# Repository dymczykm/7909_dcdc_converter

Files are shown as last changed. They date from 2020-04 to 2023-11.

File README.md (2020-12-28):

# Alpine 7909 DC/DC converter
An improved DC/DC converter design for Alpine 7909.

Uses a Traco 6W converter to get symmetric +/-12V and then ultralow noise, ultrahigh PSRR linear regulators (LT3045, LT3094) to regulate the voltages down to +/-10V.

The board is smaller than the original and fits nicely into the space available.

**Warning** The PCBs have not been tested as of now, use at your own risk.

## 3D view

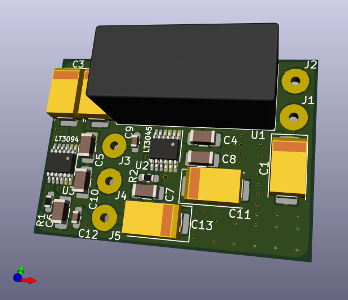
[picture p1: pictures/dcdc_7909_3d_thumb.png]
3D render


## Component list

Most components specific to this are contained in the [CSV file](digikey_bom.csv). Please note that it does not contain components I had already at hand, so double check it against the schematic.

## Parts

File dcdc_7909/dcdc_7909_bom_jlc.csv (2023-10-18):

Comment | Designator | Footprint | LCSC Part #
22u | C1,C2,C3,C6,C8,C9,C15,C16,C17,C19,C21,C22,C24,C26 | C_1210_3225Metric | C426653
100n | C4,C7,C10,C13,C14 | C_0402_1005Metric | C307331
2u2 | C5,C12 | C_1206_3216Metric | C50254
10n | C11,C20,C25 | C_0402_1005Metric | C15195
22u | C18,C23 | C_1206_3216Metric | C12891
P6SMB20A | D1 | D_SMB | C719321
600Ω@100MHz | FB1,FB2 | R_0805_2012Metric | C1017
2M2 | R1 | R_0402_1005Metric | C11490
300k | R2 | R_0402_1005Metric | C334752
499k 1% | R3 | R_0402_1005Metric | C407728
47k 1% | R4 | R_0402_1005Metric | C25792
3M32 | R5 | R_0402_1005Metric | C477691
430k | R6 | R_0402_1005Metric | C25786
6k81 | R7 | R_0402_1005Metric | C284661
19k1 1% | R8 | R_0402_1005Metric | C52036
1k78 1% | R9 | R_0402_1005Metric | C284379
100k 1% | R10,R12 | R_0603_1608Metric | C25803
1k | R11,R13 | R_0402_1005Metric | C11702
LM2940-SOT223-15 | U1 | SOT-223 | C81094
MAX17579ATC+ | U3 | 21-0664_TD1233&plus_1C_MXM | C5691155
LT3045xMSE | U4 | MSOP-12-1EP_3x4mm_P0.65mm_EP1.65x2.85mm | C666577
LT3094xMSE | U5 | MSOP-12-1EP_3x4mm_P0.65mm_EP1.65x2.85mm | C498217

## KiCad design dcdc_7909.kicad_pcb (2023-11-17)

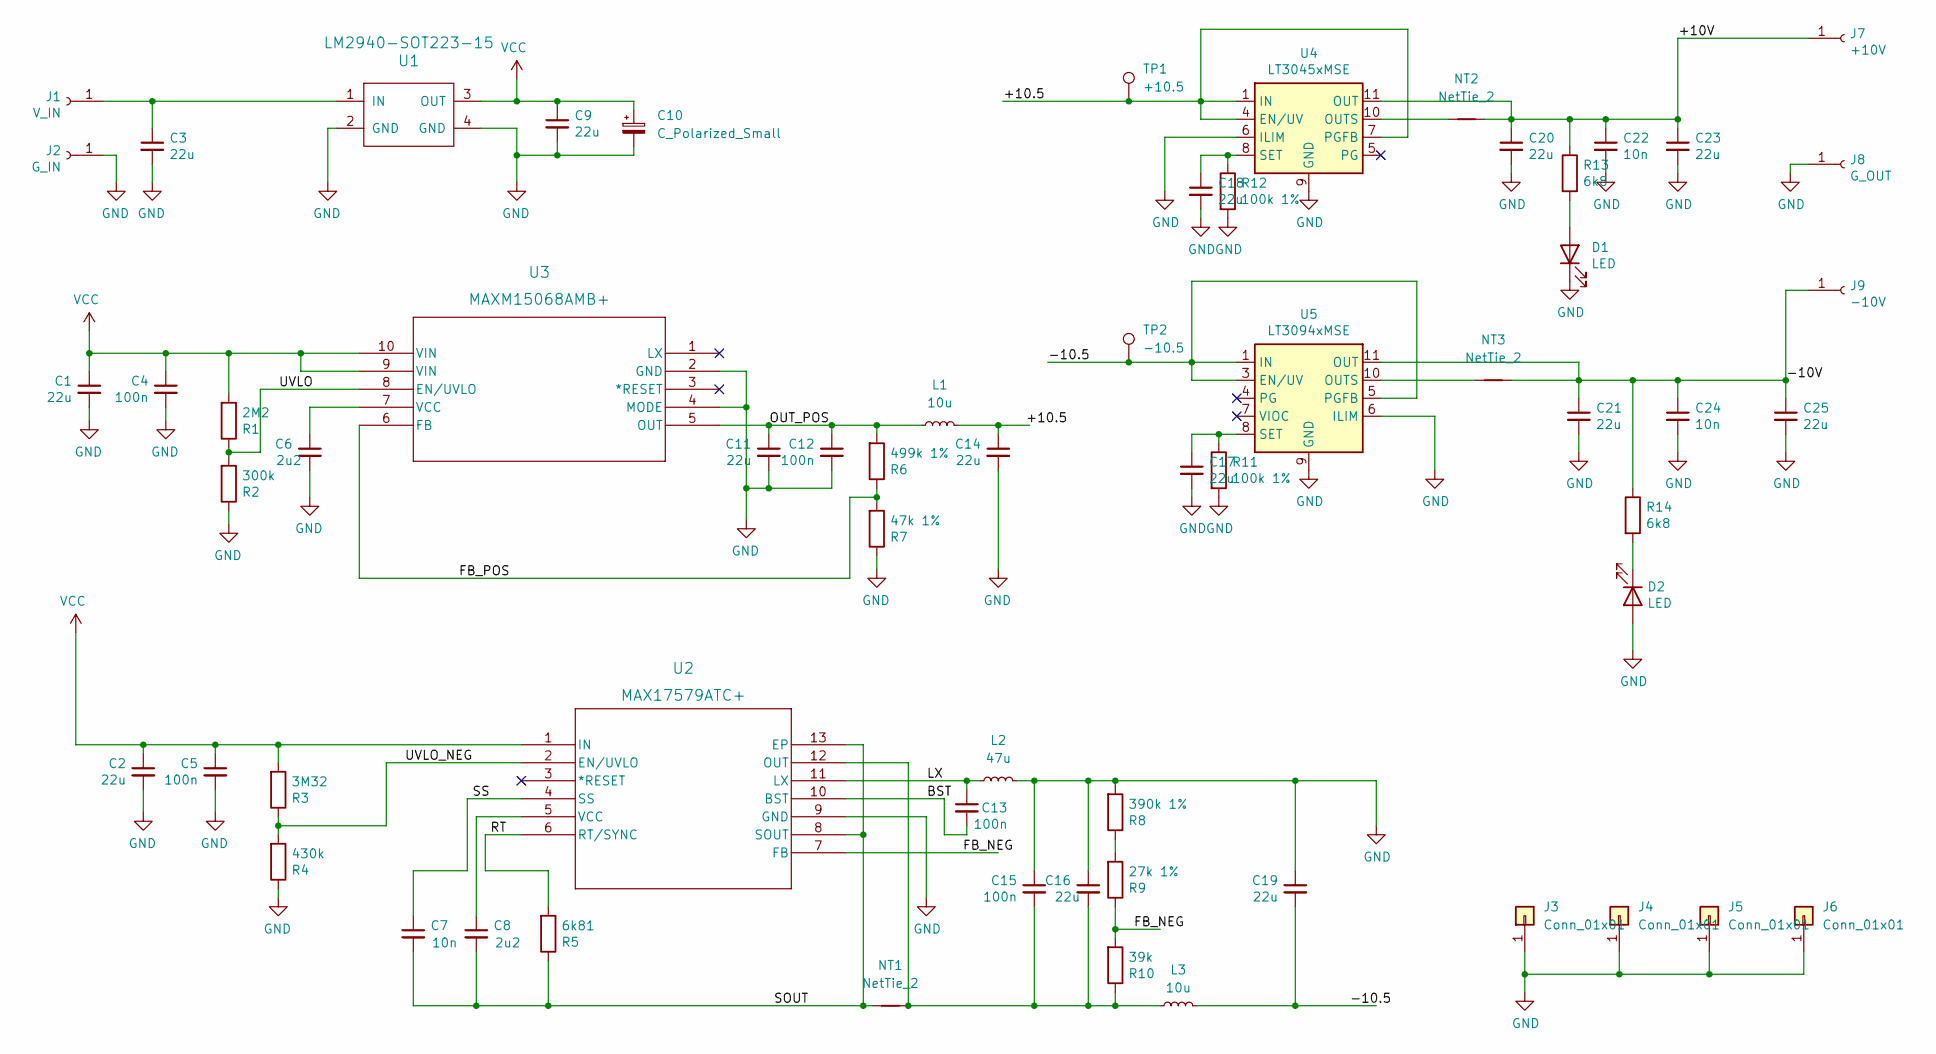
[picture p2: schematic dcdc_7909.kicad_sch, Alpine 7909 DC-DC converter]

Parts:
C1, C2, C3, C9, C11, C14, C16, C19, C20, C21, C23, C25: 22u; C_1210_3225Metric; LCSC C426653
C4, C5, C12, C13, C15: 100n; C_0402_1005Metric; LCSC C307331
C6, C8: 2u2; C_1206_3216Metric; LCSC C50254
C7, C22, C24: 10n; C_0402_1005Metric; LCSC C15195
C10: C_Polarized_Small; CP_Elec_6.3x5.9
C17, C18: 22u; C_1206_3216Metric; LCSC C12891
D1, D2: LED; LED_0805_2012Metric_Pad1.15x1.40mm_HandSolder; LCSC DO NOT POPULATE
J1: V_IN; SolderWire-0.75sqmm_1x01_D1.25mm_OD3.5mm; LCSC DO NOT POPULATE
J2: G_IN; SolderWire-0.75sqmm_1x01_D1.25mm_OD3.5mm; LCSC DO NOT POPULATE
J3, J4, J5, J6: Conn_01x01; SolderWirePad_1x01_SMD_1x2mm; LCSC DO NOT POPULATE
J7: +10V; SolderWire-0.75sqmm_1x01_D1.25mm_OD3.5mm; LCSC DO NOT POPULATE
J8: G_OUT; SolderWire-0.75sqmm_1x01_D1.25mm_OD3.5mm; LCSC DO NOT POPULATE
J9: -10V; SolderWire-0.75sqmm_1x01_D1.25mm_OD3.5mm; LCSC DO NOT POPULATE
L1, L3: 10u; L_0805_2012Metric; LCSC DO NOT POPULATE
L2: 47u; Wurth 74408063680; LCSC DO NOT POPULATE
NT1, NT2, NT3: NetTie_2; NetTie-2_SMD_Pad0.5mm; LCSC DO NOT POPULATE
R1: 2M2; R_0402_1005Metric; LCSC C11490
R2: 300k; R_0402_1005Metric; LCSC C334752
R3: 3M32; R_0402_1005Metric; LCSC C477691
R4: 430k; R_0402_1005Metric; LCSC C25786
R5: 6k81; R_0402_1005Metric; LCSC C284661
R6: 499k 1%; R_0402_1005Metric; LCSC C407728
R7: 47k 1%; R_0402_1005Metric; LCSC C25792
R8: 390k 1%; R_0402_1005Metric; LCSC C52036
R9: 27k 1%; R_0402_1005Metric; LCSC C52036
R10: 39k; R_0402_1005Metric; LCSC C284379
R11, R12: 100k 1%; R_0603_1608Metric; LCSC C25803
R13, R14: 6k8; R_0402_1005Metric; LCSC C25917
TP1: +10.5; TestPoint_THTPad_D1.0mm_Drill0.5mm; LCSC DO NOT POPULATE
TP2: -10.5; TestPoint_THTPad_D1.0mm_Drill0.5mm; LCSC DO NOT POPULATE
U1: LM2940-SOT223-15; SOT-223; LCSC C81094
U2: MAX17579ATC+; 21-0664_TD1233&plus_1C_MXM; LCSC C5691155
U3: MAXM15068AMB+; 10-eMGA (3x2.6); LCSC DO NOT POPULATE
U4: LT3045xMSE; MSOP-12-1EP_3x4mm_P0.65mm_EP1.65x2.85mm; LCSC C666577
U5: LT3094xMSE; MSOP-12-1EP_3x4mm_P0.65mm_EP1.65x2.85mm; LCSC C498217

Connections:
/+10.5: C14.1, L1.1, TP1.1, U4.1 (IN), U4.2 (IN), U4.3 (IN), U4.4 (EN/UV), U4.7 (PGFB)
/+10V: C20.1, C22.1, C23.1, J7.1, NT2.2, R13.1, U4.11 (OUT), U4.12 (OUT)
/-10.5: C19.2, L3.1, TP2.1, U5.1 (IN), U5.2 (IN), U5.3 (EN/UV), U5.5 (PGFB), U5.13 (IN)
/-10V: C21.1, C24.1, C25.1, J9.1, NT3.2, R14.1, U5.11 (OUT), U5.12 (OUT)
/BST: C13.2, U2.10 (BST)
/FB_NEG: R9.1, R10.2, U2.7 (FB)
/FB_POS: R6.1, R7.2, U3.6 (FB)
/LX: C13.1, L2.1, U2.11 (LX)
/OUT_POS: C11.1, C12.1, L1.2, R6.2, U3.5 (OUT)
/RT: R5.2, U2.6 (RT/SYNC)
/SOUT: C7.2, C8.2, NT1.1, R5.1, U2.8 (SOUT), U2.13 (EP)
/SS: C7.1, U2.4 (SS)
/UVLO: R1.1, R2.2, U3.8 (EN/UVLO)
/UVLO_NEG: R3.1, R4.2, U2.2 (EN/UVLO)
GND: C1.2, C2.2, C3.2, C4.2, C5.2, C6.2, C9.2, C10.2, C11.2, C12.2, C14.2, C15.1, C16.1, C17.2, C18.2, C19.1, C20.2, C21.2, C22.2, C23.2, C24.2, C25.2, D1.1 (K), D2.2 (A), J2.1, J3.1, J4.1, J5.1, J6.1, J8.1, L2.2, R2.1, R4.1, R7.1, R8.2, R11.2, R12.2, U1.2 (GND), U1.4 (GND), U2.9 (GND), U3.2 (GND), U3.4 (MODE), U4.6 (ILIM), U4.9 (GND), U4.13 (GND), U5.6 (ILIM), U5.9 (GND)
unnamed: C3.1, J1.1, U1.1 (IN)
unnamed: C6.1, U3.7 (VCC)
unnamed: C8.1, U2.5 (VCC)
unnamed: C15.2, C16.2, L3.2, NT1.2, R10.1, U2.12 (OUT)
unnamed: C17.1, R11.1, U5.8 (SET)
unnamed: C18.1, R12.1, U4.8 (SET)
unnamed: D1.2 (A), R13.2
unnamed: D2.1 (K), R14.2
unnamed: NT2.1, U4.10 (OUTS)
unnamed: NT3.1, U5.10 (OUTS)
unnamed: R8.1, R9.2
VCC: C1.1, C2.1, C4.1, C5.1, C9.1, C10.1, R1.2, R3.2, U1.3 (OUT), U2.1 (IN), U3.9 (VIN), U3.10 (VIN)

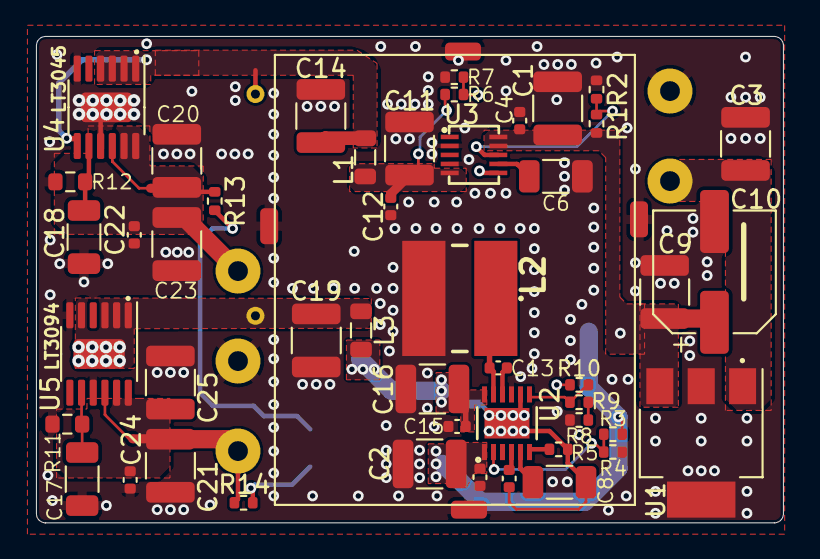
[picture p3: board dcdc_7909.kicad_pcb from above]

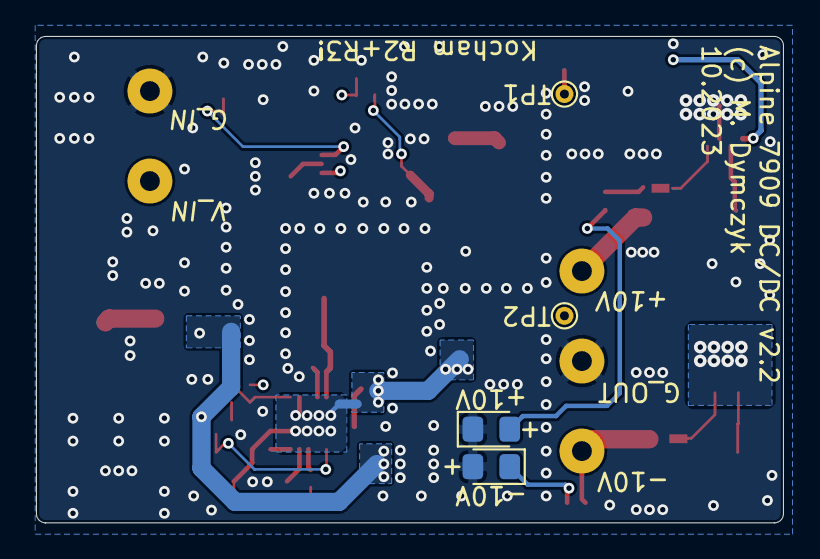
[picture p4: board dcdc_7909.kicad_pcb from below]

Board: 4 copper layers, 41.5 x 27.0 mm, 63 parts (5 on the bottom side), 27 nets.

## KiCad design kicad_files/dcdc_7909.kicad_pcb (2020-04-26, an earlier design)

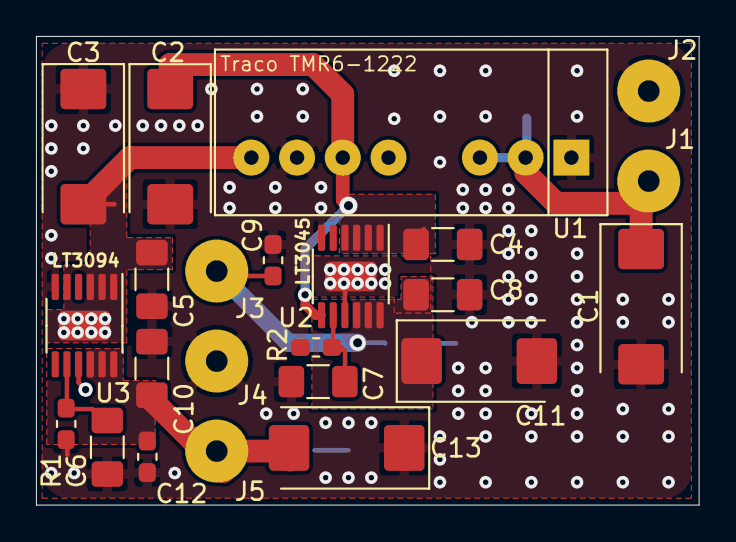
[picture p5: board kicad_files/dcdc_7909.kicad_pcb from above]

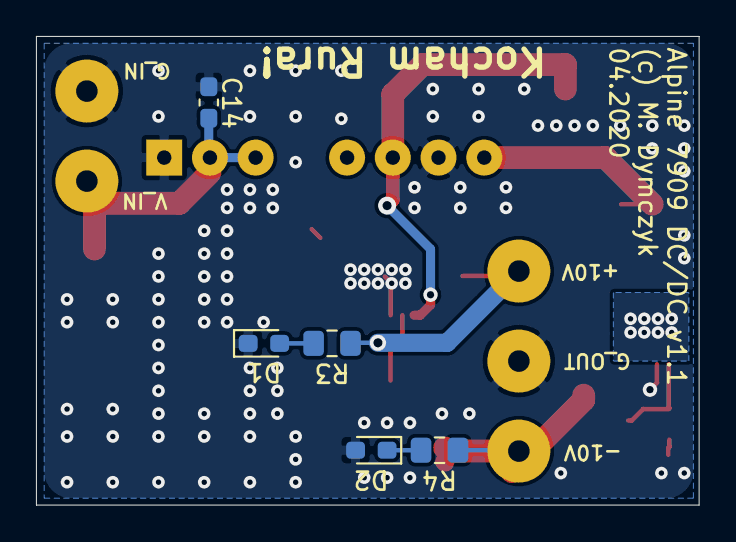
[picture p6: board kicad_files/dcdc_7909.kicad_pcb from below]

Board: 2 copper layers, 36.8 x 26.0 mm, 28 parts (5 on the bottom side), 10 nets.

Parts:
C1: 100u 25v; CP_EIA-7343-31_Kemet-D_Pad2.25x2.55mm_HandSolder
C2, C3, C11, C13: 100u 16V; CP_EIA-7343-31_Kemet-D_Pad2.25x2.55mm_HandSolder
C4, C5, C6, C7, C8, C10: 10u X7R; C_1206_3216Metric_Pad1.42x1.75mm_HandSolder
C9, C12, C14: 10n; C_0603_1608Metric_Pad1.05x0.95mm_HandSolder
D1, D2: LED; LED_0603_1608Metric_Pad1.05x0.95mm_HandSolder
J1: V_IN; SolderWirePad_1x01_Drill1.2mm
J2: G_IN; SolderWirePad_1x01_Drill1.2mm
J3: +10V; SolderWirePad_1x01_Drill1.2mm
J4: G_OUT; SolderWirePad_1x01_Drill1.2mm
J5: -10V; SolderWirePad_1x01_Drill1.2mm
R1, R2: 100k; R_0603_1608Metric_Pad1.05x0.95mm_HandSolder
R3, R4: 820; R_0805_2012Metric_Pad1.15x1.40mm_HandSolder
U1: TMR6; Traco_TMR6
U2: LT3045xMSE; MSOP-12-1EP_3x4mm_P0.65mm_EP1.65x2.85mm
U3: LT3094xMSE; MSOP-12-1EP_3x4mm_P0.65mm_EP1.65x2.85mm

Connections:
+12V: C8.1, C9.1, C11.1, J3.1, R3.1, U2.10, U2.11, U2.12
-12V: C10.1, C12.1, C13.2, J5.1, R4.1, U3.10, U3.11, U3.12
GND: C1.2, C2.2, C3.1, C4.2, C5.2, C6.2, C7.2, C8.2, C9.2, C10.2, C11.2, C12.2, C13.1, C14.2, D1.1, D2.2, J2.1, J4.1, R1.2, R2.2, U1.1, U1.7, U2.6, U2.9, U2.13, U3.6, U3.9
unnamed: C2.1, C4.1, U1.6, U2.1, U2.2, U2.3, U2.4, U2.7
unnamed: C3.2, C5.1, U1.8, U3.1, U3.2, U3.3, U3.5, U3.13
unnamed: C6.1, R1.1, U3.8
unnamed: C7.1, R2.1, U2.8
unnamed: D1.2, R3.2
unnamed: D2.1, R4.2
VCC: C1.1, C14.1, J1.1, U1.2, U1.3

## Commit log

2020-04-25 design v1.0
    [dcdc_7909.kicad_pcb, dcdc_7909.sch]
2020-04-26 v1.1 finished, gerber files added
    [dcdc_7909-B_Cu.gbr, dcdc_7909-B_Mask.gbr, dcdc_7909-B_SilkS.gbr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]
2020-12-28 Update the files.
    [dcdc_7909.kicad_pcb, dcdc_7909.sch, digikey_bom.csv]
2023-06-28 working on v2.
    [dcdc_7909.kicad_sch]
2023-06-30 V2 PCB almost finished.
    [dcdc_7909.kicad_pcb, dcdc_7909.kicad_sch]
2023-07-02 One more iteration over the PCB to fit the filtering in the can.
    [dcdc_7909.kicad_pcb, dcdc_7909.kicad_sch]
2023-07-03 Updated ground fill zones.
    [dcdc_7909.kicad_pcb, dcdc_7909.kicad_sch, digikey_bom.csv]
2023-07-03 Updated BOM.
    [dcdc_7909.kicad_pcb, dcdc_7909.kicad_sch]
2023-07-04 Corrected the ground plane.
    [dcdc_7909.kicad_pcb, dcdc_7909.kicad_sch]
2023-07-05 New version ready for JLCPCB.
    [dcdc_7909-B_Cu.gbr, dcdc_7909-B_Mask.gbr, dcdc_7909-B_SilkS.gbr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]
2023-08-01 Files send for production.
    [dcdc_7909-B_Cu.gbr, dcdc_7909-B_Mask.gbr, dcdc_7909-B_Paste.gbr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]
2023-08-10 WIP on version 2.1, routing mostly done.
    [dcdc_7909.kicad_pcb, dcdc_7909.kicad_sch]
2023-08-11 Rev 2.1 finished.
    [dcdc_7909.kicad_pcb, dcdc_7909.kicad_sch]
2023-08-11 Final v2.1.
    [dcdc_7909.kicad_pcb, dcdc_7909.kicad_sch]
2023-08-13 Initial commit of the production files, not final yet!
    [dcdc_7909.csv, dcdc_7909_bom_jlc.csv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]
2023-08-13 V2.1 ready for JLCPCB.
    [dcdc_7909-B_Cu.gbr, dcdc_7909-B_Mask.gbr, dcdc_7909-B_Paste.gbr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]
2023-09-21 Reworking the board with MAX76x/
    [dcdc_7909.kicad_pcb, dcdc_7909.kicad_sch]
2023-09-21 Reworking almost completed.
    [dcdc_7909.kicad_pcb, dcdc_7909.kicad_sch]
2023-09-23 Ready design, but MAX764 cannot be used because of the Vin-Vout differential.
    [dcdc_7909.csv, dcdc_7909.kicad_pcb, dcdc_7909.kicad_sch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]
2023-09-26 Switched to MAX77x + Si9435.
    [dcdc_7909.kicad_pcb, dcdc_7909.kicad_sch]
2023-10-06 Last version before switching to Maxim modules.
    [dcdc_7909.kicad_pcb]
2023-10-06 Added MAXM15068.
    [dcdc_7909.kicad_sch]
2023-10-06 New version based on MAXM15068 and MAX17579.
    [dcdc_7909.kicad_pcb, dcdc_7909.kicad_sch]
2023-10-06 Calculated the resistor values.
    [dcdc_7909.kicad_sch]
2023-10-06 Filled out LCSC components refs.
    [dcdc_7909.kicad_sch]
2023-10-18 Fixed the 2u2 cap footprints.
    [dcdc_7909.csv, dcdc_7909.kicad_sch, dcdc_7909_bom_jlc.csv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]
2023-10-18 Sent for production.
    [dcdc_7909.csv, dcdc_7909.kicad_pcb, dcdc_7909.kicad_sch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]
2023-11-15 Doing calcs + removing caps that might introduce noise.
    [dcdc_7909.kicad_pcb, dcdc_7909.kicad_sch]
2023-11-15 Before restructuring max17579.
    [dcdc_7909.kicad_pcb, dcdc_7909.kicad_sch]
2023-11-17 Fix footprints of MAX and MAXM.
    [dcdc_7909.kicad_pcb, dcdc_7909.kicad_sch]
